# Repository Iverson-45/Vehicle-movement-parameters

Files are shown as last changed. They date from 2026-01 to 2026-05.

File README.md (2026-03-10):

Vehicle Movement Parameters Meter 
------

Authors: Jakub Litwin, Mateusz Prądziński, Adrian Andrószowski, Błażej Szkobel 
Overview

The goal of this project is to design and build a prototype device capable of measuring, calculating, and displaying real-time vehicle movement parameters. To ensure high data throughput, low latency, and a responsive UI, the system utilizes a Dual-MCU architecture that effectively splits the workload between sensor processing and data logging/display.
Calculated & Displayed Parameters:

    Speed: [km/h] 

    Acceleration: [m/s^2] (Instantaneous acceleration) 

    Power: [Hp] 

    Torque: [Nm] 

    Inclination: [°] (Pitch / Roll) 

Hardware Architecture

The device operates on two separate microcontrollers communicating via UART.

1. Main MCU (Data Processor)

    Microcontroller: STM32F411CEU6 

    Role: Handles all sensor data acquisition, scaling, filtration, and complex sensor fusion algorithms.

    Sensors: U-blox NEO-M8N (GPS) and BMI160 (IMU + Gyroscope).

2. Secondary MCU (Display & Logger)

    Microcontroller: STM32f303k8 

    Role: Receives processed numerical data from the Main MCU and handles the user interface.

    Peripherals: Drives a 2.0-inch TFT SPI Display and handles .csv data logging to a microSD card.

Firmware & Communication

    Main MCU: Programmed in low-level C (registers) to highly optimize the code for its specific tasks. It uses interrupt-driven peripherals to minimize delays and ensure smooth data reception. It synchronizes 100 data reads per second from the BMI160 and 5 reads per second from the GPS.

    Auxiliary MCU: Written in C utilizing the HAL library. It implements heavily optimized external libraries from GitHub for the ST7789 display and SPI SD card.

    Inter-MCU Communication: The two microcontrollers communicate via UART. At startup, they perform a handshake to initiate communication. The Aux MCU sends the user-defined vehicle mass to the Main MCU, and the Main MCU continuously streams back the calculated data.

How It Works: Algorithms & Calibration

To make the device user-friendly, it does not require perfectly leveled physical mounting inside the vehicle. Instead, the data passes through a complex algorithmic pipeline divided into three distinct phases:

Phase 1: Gravity Calibration While the vehicle is completely stationary, the device measures the Earth's gravitational pull to determine the gravity vector relative to the device's physical orientation. This establishes the true Z-axis (downward force).

Phase 2: Longitudinal Axis Calibration (Direction) The user performs a short, straight-line acceleration. The device detects this forward motion vector to define the X-axis (front). Using the cross product of these established forces, the software builds an orthonormal basis. This creates a 3D rotation matrix that mathematically rotates all raw sensor vectors to perfectly align with the vehicle's actual coordinate system, automatically compensating for any "crooked" mounting.

Phase 3: Active Operation During driving, raw data from the accelerometer and gyroscope is continuously transformed using the generated rotation matrix. The system calculates the device's tilt angles from the accelerometer and applies a Complementary Filter to fuse this data with the gyroscope readings for smooth, accurate inclination and acceleration outputs.
Current State & Future Development

Semester 1 Achievements:
A fully working prototype has been built that successfully handles instrument communication, calibration algorithms, the user interface, display presentation, and SD card .csv logging.

Next Steps (Semester 2 Goals): 

    Design a dedicated power supply section.

    Create a complete device schematic and custom PCB layout.

    Design a physical 3D enclosure/case.

    Conduct extensive real-world measurement tests.

    Develop PC software to visualize the saved telemetry data.

## Preliminary Measurement Results



During our initial field tests, the logged telemetry data was extracted and visualized using Python. We are pleased to report that the calculated power output closely aligns with the actual specifications of the vehicle used for testing.

**⚠️ Note:** Please keep in mind that this is an early prototype and not the final version of the system. The hardware architecture and calculation algorithms are still actively being refined. Further calibration, optimization, and extensive real-world validations are planned for the upcoming semester.

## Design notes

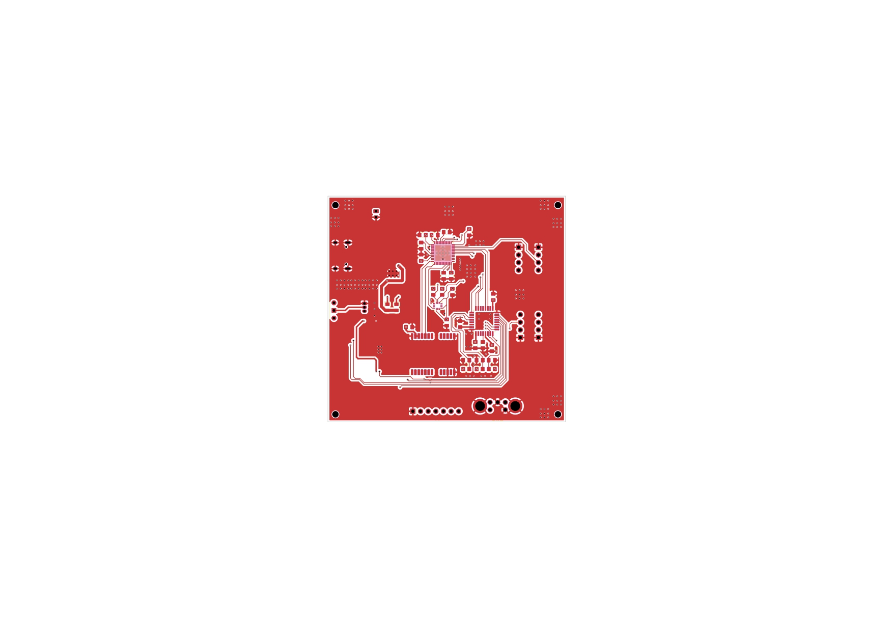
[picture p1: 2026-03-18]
Schematic/Screens/SIDEF_page-0001.jpg

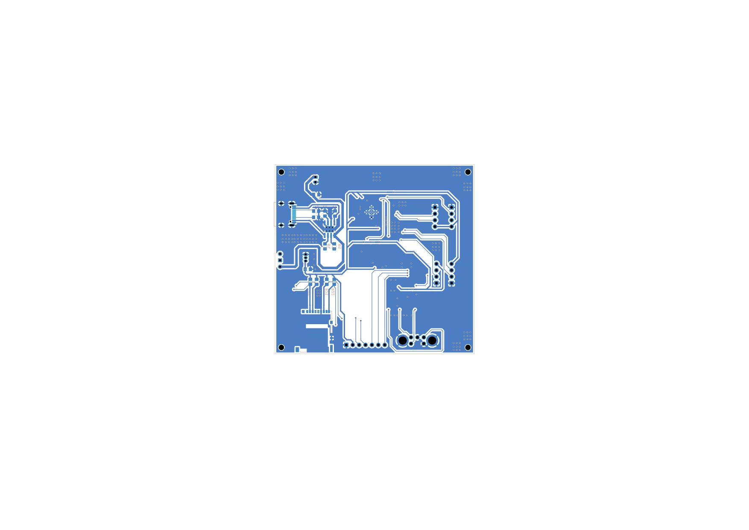
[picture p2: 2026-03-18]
Schematic/Screens/SIDEB_page-0001.jpg

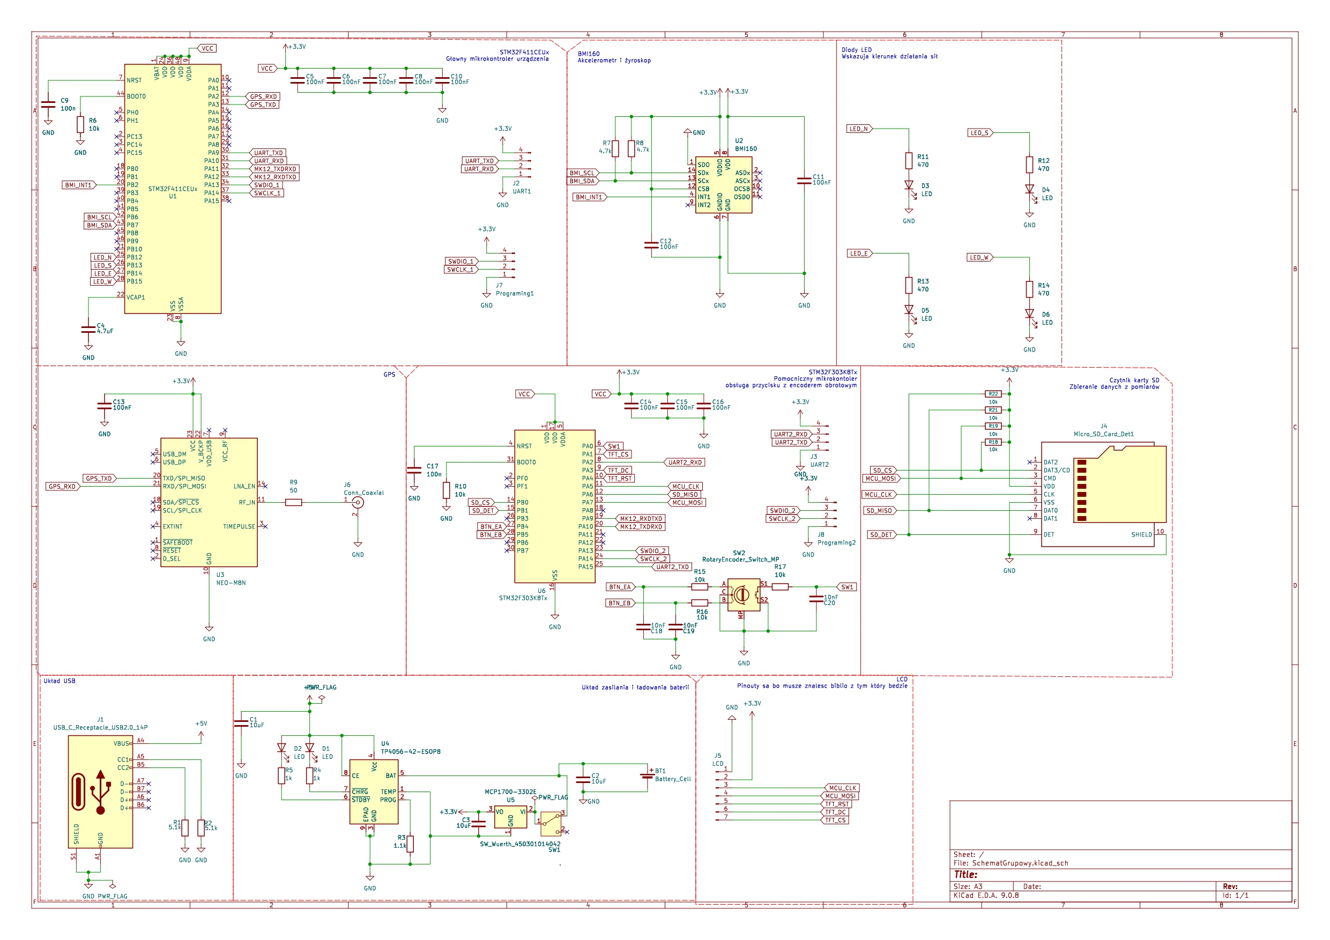
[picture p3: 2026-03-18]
Schematic/Screens/SchematGrupowy_page-0001.jpg

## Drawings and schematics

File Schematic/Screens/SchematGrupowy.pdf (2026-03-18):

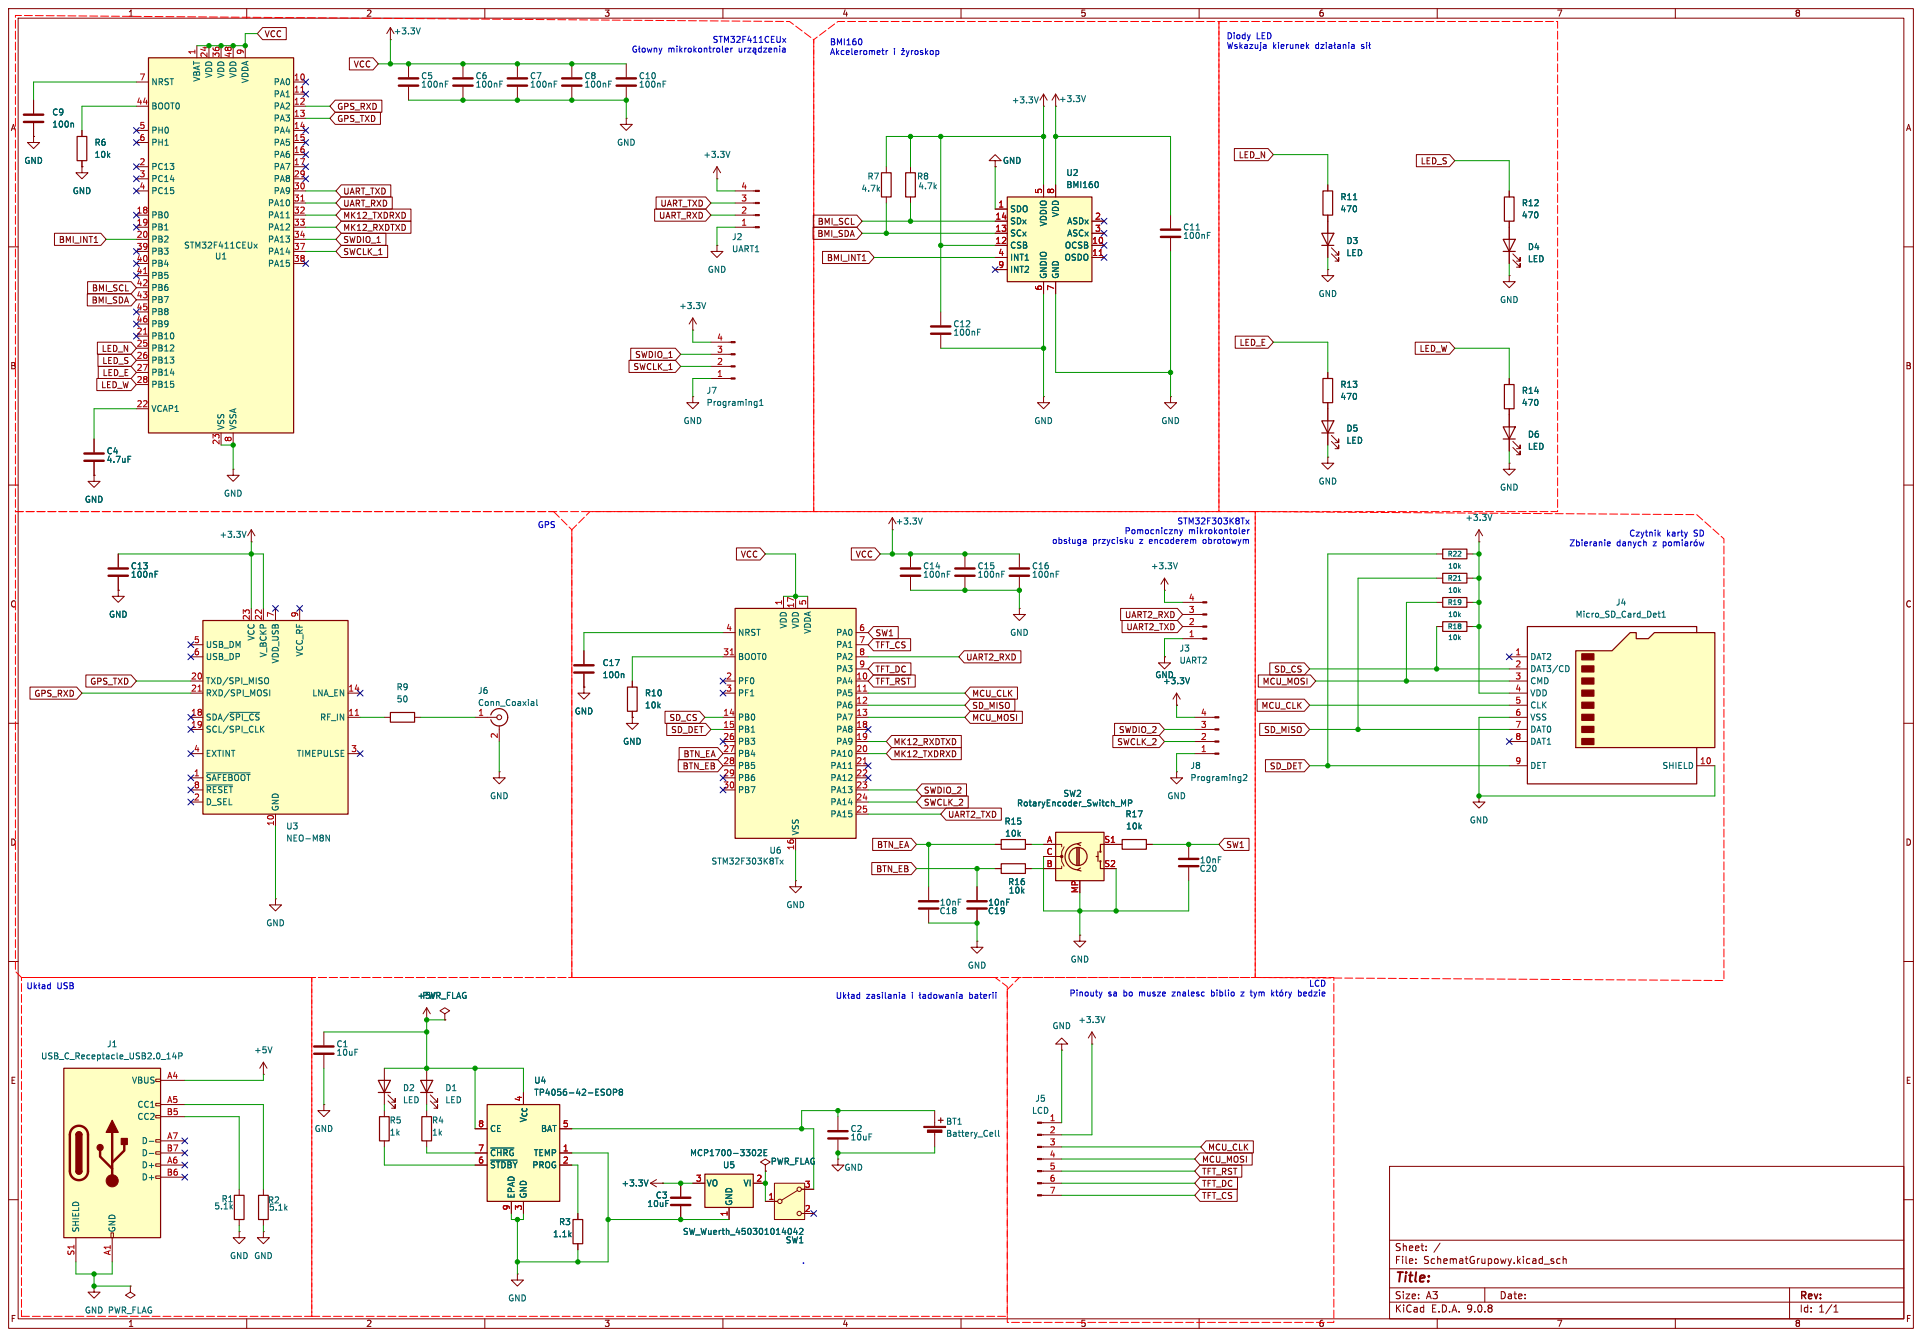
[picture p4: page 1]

1 VDD 24 VDD 36 VSS 23 VDD 48 VSSA

7 ASDx 2 ASCx 3 OCSB 10 OSDO 11 GND

7 ASDx 2 ASCx 3 OCSB 10 OSDO 11 U2BMI160 R19

3 BAT 5 TEMP 1 PROG 2 U4 TP4056-42-ESOP8 GND

Pinouty sa bo musze znalesc biblio z tym þÿktóry bedzie

Id: 1/1 Title: File: SchematGrupowy.kicad_sch Sheet: /

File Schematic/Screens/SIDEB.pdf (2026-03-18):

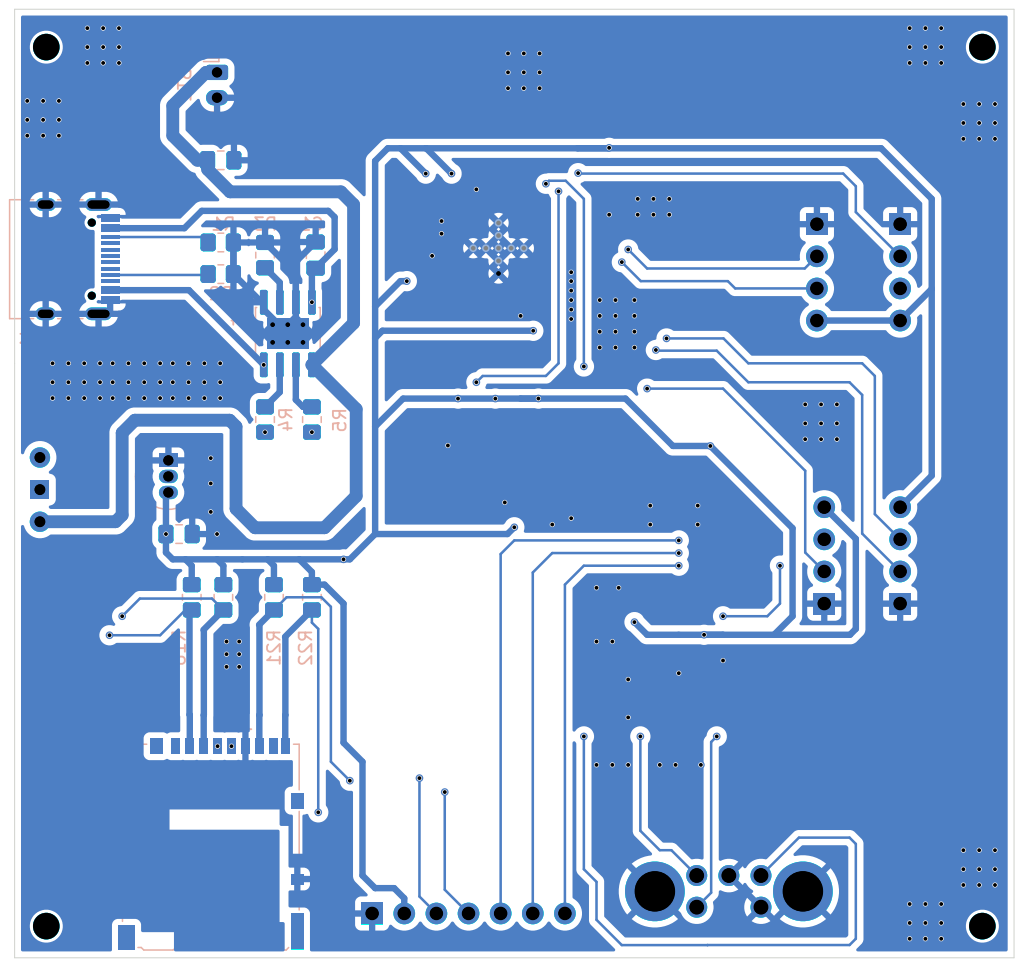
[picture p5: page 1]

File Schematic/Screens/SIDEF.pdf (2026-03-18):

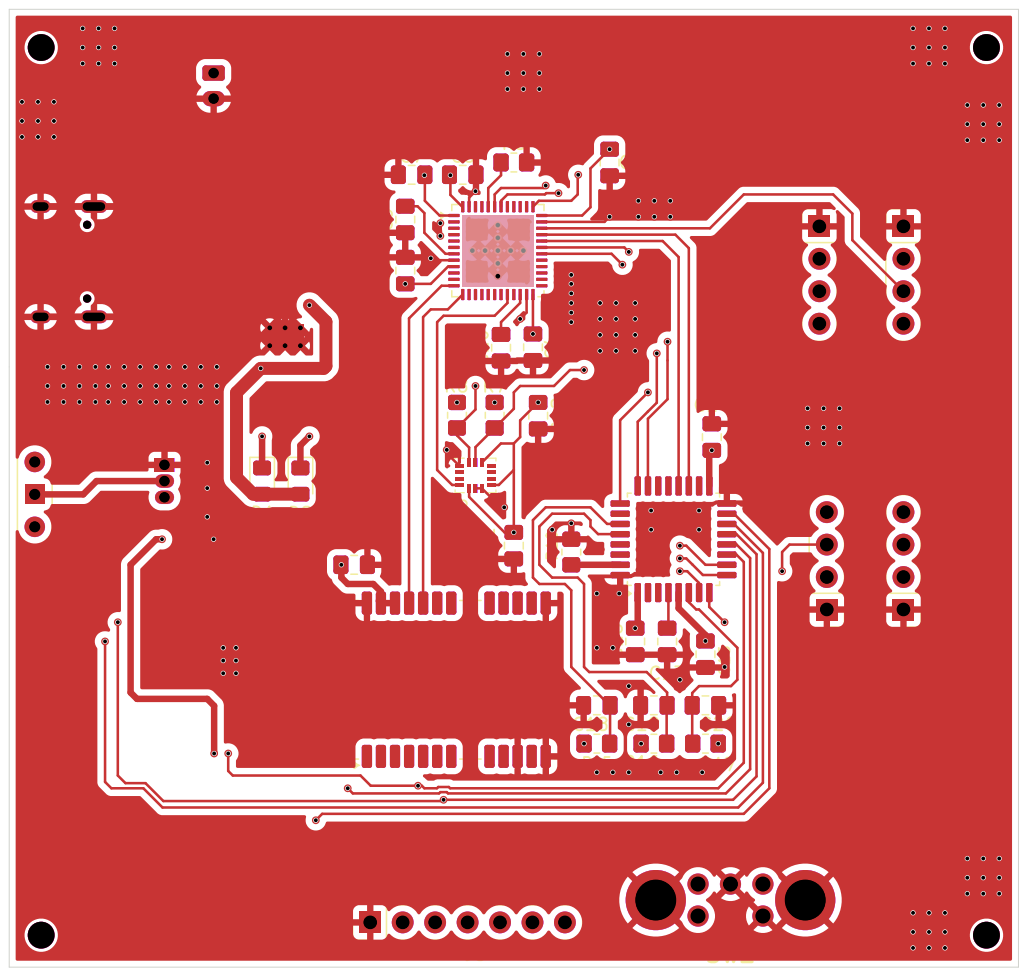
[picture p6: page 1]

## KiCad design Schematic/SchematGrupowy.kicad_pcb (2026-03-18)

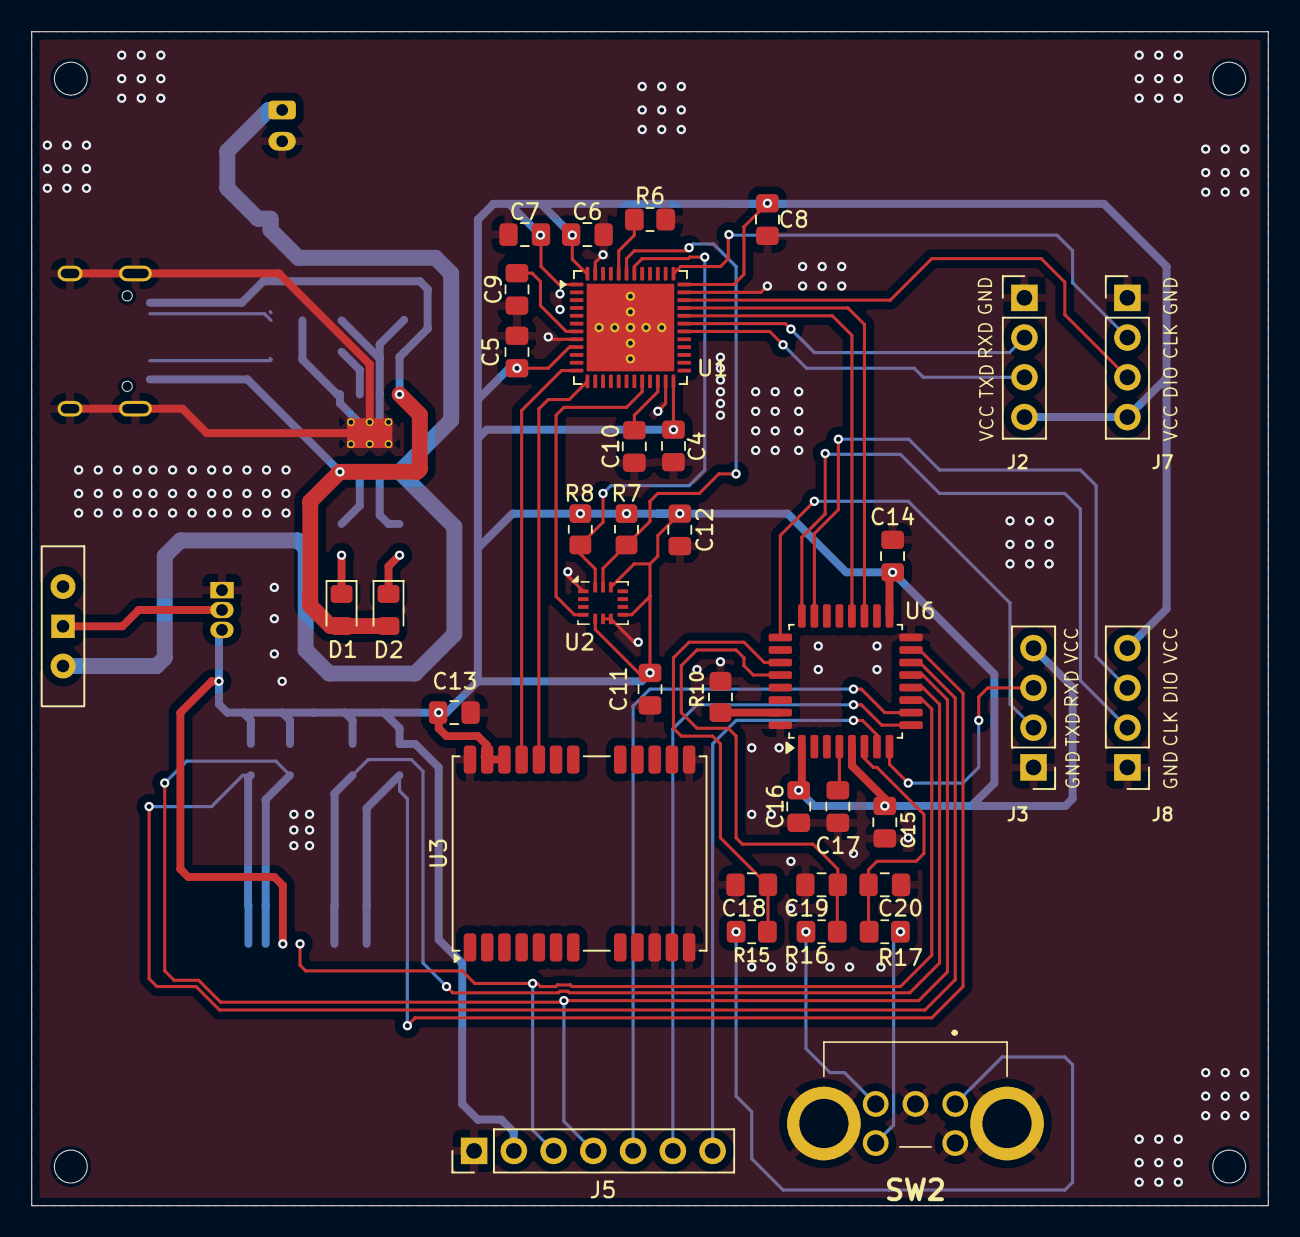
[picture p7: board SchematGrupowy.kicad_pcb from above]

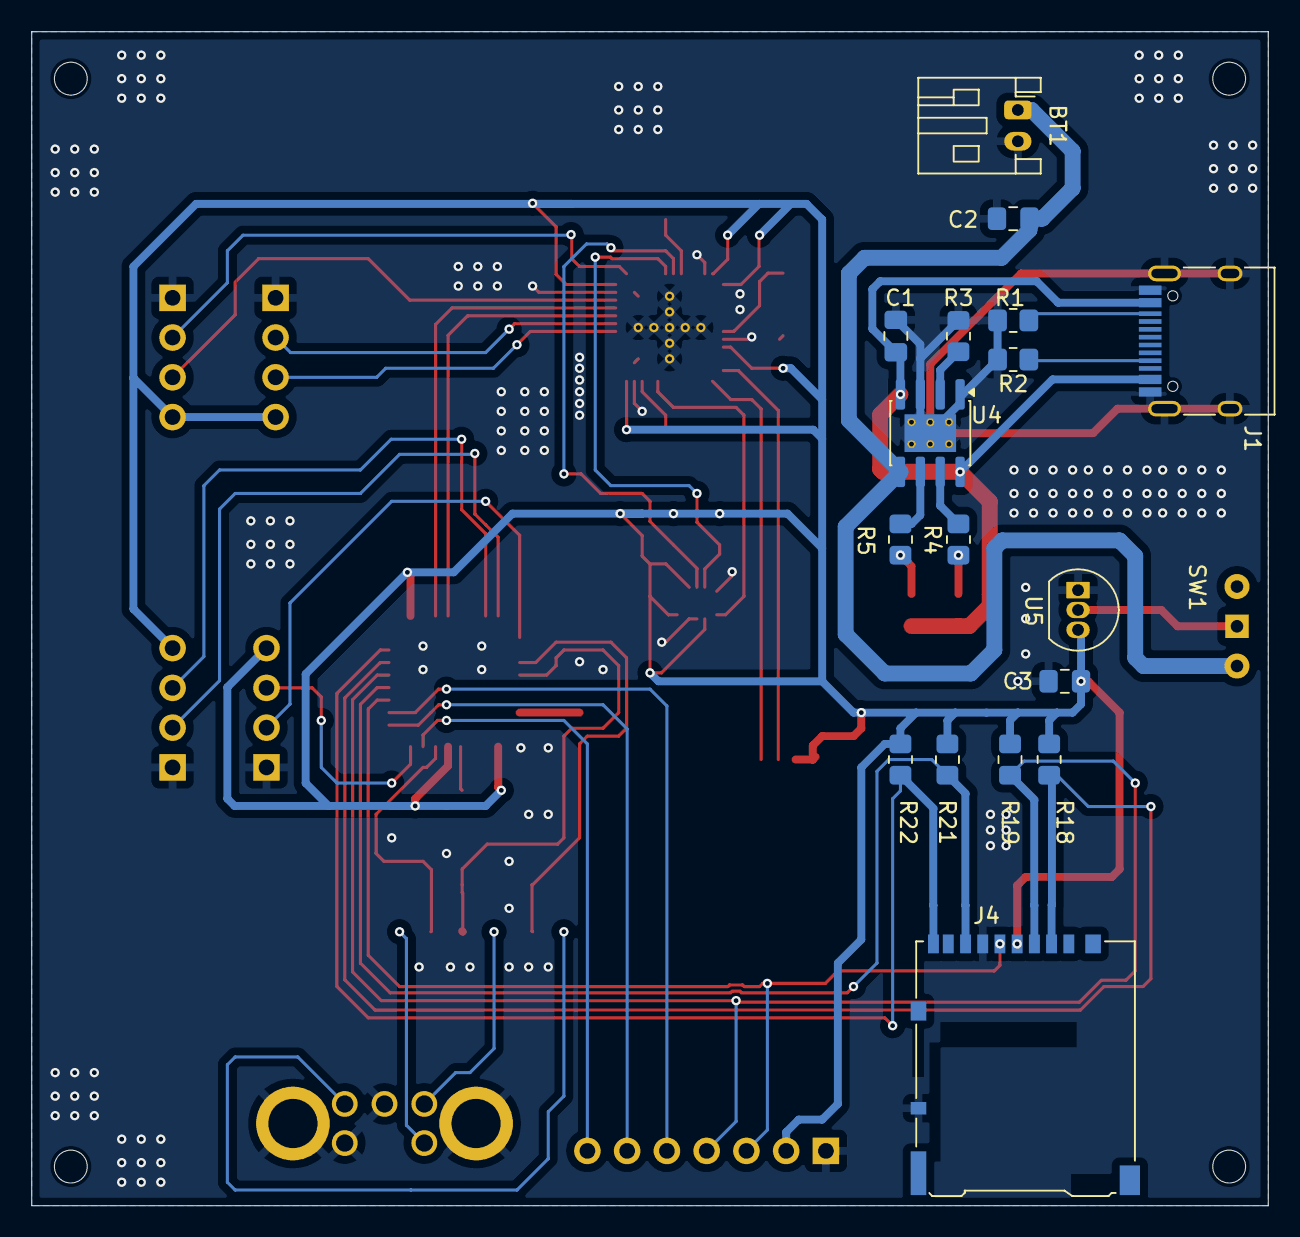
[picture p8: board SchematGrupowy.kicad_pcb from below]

Board: 2 copper layers, 79.0 x 75.0 mm, 54 parts (17 on the bottom side), 46 nets.

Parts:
BT1: Battery_Cell; JST_PH_S2B-PH-K_1x02_P2.00mm_Horizontal
C1, C2, C3: 10uF; C_0805_2012Metric_Pad1.18x1.45mm_HandSolder
C4: 4.7uF; C_0805_2012Metric_Pad1.18x1.45mm_HandSolder
C5, C6, C7, C8, C10, C11, C12, C13, C14, C15, C16: 100nF; C_0805_2012Metric_Pad1.18x1.45mm_HandSolder
C9, C17: 100n; C_0805_2012Metric_Pad1.18x1.45mm_HandSolder
C18, C19, C20: 10nF; C_0805_2012Metric_Pad1.18x1.45mm_HandSolder
D1, D2: LED; LED_0805_2012Metric_Pad1.15x1.40mm_HandSolder
J1: USB_C_Receptacle_USB2.0_14P; USB_C_Receptacle_HRO_TYPE-C-31-M-12
J2: UART1; PinHeader_1x04_P2.54mm_Vertical
J3: UART2; PinHeader_1x04_P2.54mm_Vertical
J4: Micro_SD_Card_Det1; microSD_HC_Hirose_DM3AT-SF-PEJM5
J5: LCD; PinHeader_1x07_P2.54mm_Vertical
J7: Programing1; PinHeader_1x04_P2.54mm_Vertical
J8: Programing2; PinHeader_1x04_P2.54mm_Vertical
R1, R2: 5.1k; R_0805_2012Metric_Pad1.20x1.40mm_HandSolder
R3: 1.1k; R_0805_2012Metric_Pad1.20x1.40mm_HandSolder
R4, R5: 1k; R_0805_2012Metric_Pad1.20x1.40mm_HandSolder
R6, R10, R15, R16, R17, R18, R19, R21, R22: 10k; R_0805_2012Metric_Pad1.20x1.40mm_HandSolder
R7, R8: 4.7k; R_0805_2012Metric_Pad1.20x1.40mm_HandSolder
SW1: SW_Wuerth_450301014042; SW_Slide-03_Wuerth-WS-SLTV_10x2.5x6.4_P2.54mm
SW2: RotaryEncoder_Switch_MP; EC11B15242AE
U1: STM32F411CEUx; QFN-48-1EP_7x7mm_P0.5mm_EP5.6x5.6mm
U2: BMI160; Bosch_LGA-14_3x2.5mm_P0.5mm
U3: NEO-M8N; ublox_NEO
U4: TP4056-42-ESOP8; SOIC-8-1EP_3.9x4.9mm_P1.27mm_EP2.41x3.3mm_ThermalVias
U5: MCP1700-3302E; TO-92_Inline
U6: STM32F303K8Tx; LQFP-32_7x7mm_P0.8mm

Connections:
+5V: C1.1, D1.2 (A), D2.2 (A), J1.A4 (VBUS), J1.A9 (VBUS), J1.B4 (VBUS), J1.B9 (VBUS), U4.4 (V_{CC}), U4.8 (CE)
BMI_INT1: U1.20 (PB2), U2.4 (INT1)
BMI_SCL: R8.2, U1.42 (PB6), U2.14 (SDx)
BMI_SDA: R7.2, U1.43 (PB7), U2.13 (SCx)
BTN_EA: C18.2, R15.1, U6.27 (PB4)
BTN_EB: C19.2, R16.2, U6.28 (PB5)
GND: BT1.2 (-), C1.2, C2.2, C3.2, C4.2, C5.2, C6.2, C7.2, C8.2, C9.2, C10.2, C11.2, C12.2, C13.2, C14.2, C15.2, C16.2, C17.2, C18.1, C19.1, C20.1, J1.A1 (GND), J1.A12 (GND), J1.B1 (GND), J1.B12 (GND), J1.S1 (SHIELD), J2.1, J3.1, J4.6 (VSS), J4.10 (SHIELD), J5.1, J7.1, J8.1, R1.2, R2.1, R3.2, R6.2, R10.2, SW2.C, SW2.MP, SW2.S2, U1.8 (VSSA), U1.23 (VSS), U1.35 (VSS), U1.47 (VSS), U1.49 (VSS), U2.1 (SDO), U2.6 (GNDIO), U2.7 (GND), U3.10 (GND), U3.12 (GND), U3.13 (GND), U3.24 (GND), U4.1 (TEMP), U4.3 (GND), U4.9 (EPAD), U5.1 (GND), U6.16 (VSS), U6.32 (VSS)
GPS_RXD: U1.12 (PA2), U3.21 (RXD/SPI_MOSI)
GPS_TXD: U1.13 (PA3), U3.20 (TXD/SPI_MISO)
MCU_CLK: J4.5 (CLK), J5.3, U6.11 (PA5)
MCU_MOSI: J4.3 (CMD), J5.4, R19.1, U6.13 (PA7)
MK12_RXDTXD: U1.33 (PA12), U6.19 (PA9)
MK12_TXDRXD: U1.32 (PA11), U6.20 (PA10)
unnamed: BT1.1 (+), C2.1, SW1.3 (A), U4.5 (BAT)
unnamed: D1.1 (K), R4.1
unnamed: D2.1 (K), R5.1
unnamed: J1.A5 (CC1), R2.2
unnamed: J1.B5 (CC2), R1.1
unnamed: R15.2, SW2.A
unnamed: R16.1, SW2.B
unnamed: R17.1, SW2.S1
unnamed: SW1.1 (B), U5.2 (VI)
unnamed: R6.1, U1.44 (BOOT0)
unnamed: C9.1, U1.7 (NRST)
unnamed: C4.1, U1.22 (VCAP1)
unnamed: R3.1, U4.2 (PROG)
unnamed: R4.2, U4.7 (~CHRG)
unnamed: R5.2, U4.6 (~STDBY)
unnamed: R10.1, U6.31 (BOOT0)
unnamed: C17.1, U6.4 (NRST)
SD_CS: J4.2 (DAT3/CD), R18.1, U6.14 (PB0)
SD_DET: J4.9 (DET), R22.1, U6.15 (PB1)
SD_MISO: J4.7 (DAT0), R21.1, U6.12 (PA6)
SW1: C20.2, R17.2, U6.6 (PA0)
SWCLK_1: J7.2, U1.37 (PA14)
SWCLK_2: J8.2, U6.24 (PA14)
SWDIO_1: J7.3, U1.34 (PA13)
SWDIO_2: J8.3, U6.23 (PA13)
TFT_CS: J5.7, U6.7 (PA1)
TFT_DC: J5.6, U6.9 (PA3)
TFT_RST: J5.5, U6.10 (PA4)
UART2_RXD: J3.3, U6.8 (PA2)
UART2_TXD: J3.2, U6.25 (PA15)
UART_RXD: J2.2, U1.31 (PA10)
UART_TXD: J2.3, U1.30 (PA9)
VCC: C3.1, C5.1, C6.1, C7.1, C8.1, C10.1, C11.1, C12.1, C13.1, C14.1, C15.1, C16.1, J2.4, J3.4, J4.4 (VDD), J5.2, J7.4, J8.4, R7.1, R8.1, R18.2, R19.2, R21.2, R22.2, U1.1 (VBAT), U1.9 (VDDA), U1.24 (VDD), U1.36 (VDD), U1.48 (VDD), U2.5 (VDDIO), U2.8 (VDD), U2.12 (CSB), U3.22 (V_BCKP), U3.23 (VCC), U5.3 (VO), U6.1 (VDD), U6.5 (VDDA), U6.17 (VDD)

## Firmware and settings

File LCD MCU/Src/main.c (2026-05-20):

#include "main.h"
#include "fatfs.h"
#include "dma.h"
#include "spi.h"
#include "usart.h"
#include "gpio.h"
#include "tim.h"
#include <string.h>
#include <stdio.h>
#include "utils.h"
#include "input_handler.h"
#include "sd_logger.h"
#include "app_ui.h"

#define RX_BUFFER_SIZE 64

typedef struct {
    int32_t speed;
    float   accel;
    int32_t pitch;
    int32_t roll;
    uint8_t count;
} AvgAccumulator;

AppState_t      currentAppState = STATE_INIT;
TelemetryData_t telemetryData = {0};

uint8_t  rxBufferIndex = 0;
uint8_t  rxByte;
volatile uint8_t isLineReady = 0;
uint8_t  uiRefreshRequest = 0;
char rxBuffer[RX_BUFFER_SIZE];

static AvgAccumulator sdAccumulator = {0};
static AvgAccumulator displayAccumulator = {0};

void SystemClock_Config(void);
void ProcessUARTLine(void);

int main(void)
{
  HAL_Init();
  SystemClock_Config();
  MX_GPIO_Init();
  MX_DMA_Init();
  MX_SPI1_Init();
  MX_USART1_UART_Init();
  MX_USART2_UART_Init();
  MX_TIM3_Init();
  MX_FATFS_Init();

  HAL_GPIO_WritePin(SD_CS_GPIO_Port, SD_CS_Pin, GPIO_PIN_SET);

  Input_Init(&htim3);
  Logger_Init();
  UI_Init();
  HAL_UART_Receive_IT(&huart1, &rxByte, 1);

  currentAppState = STATE_SPLASH;
  UI_ShowSplashScreen();

  uint32_t splashTimer = HAL_GetTick();
  uint8_t splashPromptDisplayed = 0;
  static AppState_t previousAppState = STATE_INIT;

  uint32_t lastPingTime = 0;
  uint32_t startTime = 0;

  static uint8_t calibrationStateInitialized = 0;
  static uint32_t calibrationTimer = 0;
  static uint32_t lastCalibPing = 0;

  while (1)
  {
      Input_Process(&currentAppState, &uiRefreshRequest);

      if (currentAppState == STATE_SPLASH) {
          if (!splashPromptDisplayed && (HAL_GetTick() - splashTimer > 1000)) {
              UI_ShowSplashPrompt();
              splashPromptDisplayed = 1;
          }
      }

      if (previousAppState == STATE_SPLASH && currentAppState == STATE_CONNECTING) {
          UI_ShowConnectionStatus(0);
          lastPingTime = HAL_GetTick();
          startTime = HAL_GetTick();
      }
      previousAppState = currentAppState;

      if (isLineReady) {
          ProcessUARTLine();
          isLineReady = 0;
          rxBufferIndex = 0;
          memset(rxBuffer, 0, RX_BUFFER_SIZE);
      }

      if (currentAppState == STATE_CONNECTING) {
          if (HAL_GetTick() - lastPingTime > 500) {
              uint8_t pingChar = 'd';
              HAL_UART_Transmit(&huart1, &pingChar, 1, 10);
              lastPingTime = HAL_GetTick();
          }
          if (HAL_GetTick() - startTime > 10000) {
              UI_ShowConnectionStatus(2);
              HAL_Delay(2000);
              NVIC_SystemReset();
          }
      }
      else if (currentAppState == STATE_CALIBRATION) {
          if (calibrationStateInitialized == 0) {
              calibrationTimer = HAL_GetTick();
              lastCalibPing = HAL_GetTick();
              calibrationStateInitialized = 1;
          }

          if ((HAL_GetTick() - calibrationTimer) > 2000) {
              if (HAL_GetTick() - lastCalibPing > 200) {
                  uint8_t msg = 'k';
                  HAL_UART_Transmit(&huart1, &msg, 1, 10);
                  lastCalibPing = HAL_GetTick();
              }
          }
      } else {
          calibrationStateInitialized = 0;
      }

      Logger_FlushBuffer();

      if (currentAppState == STATE_MEASUREMENT) {
          if (Logger_GetStatus() == SD_READY && !Logger_IsFileOpen()) {
               Logger_StartNewFile();
          }
      }

      if (uiRefreshRequest > 0 && currentAppState != STATE_CONNECTING) {
          UI_Update(currentAppState, &uiRefreshRequest, &telemetryData);
      }
  }
}

void HAL_UART_RxCpltCallback(UART_HandleTypeDef *huart) {
    if (huart->Instance == USART1) {
        if (rxByte == '\n' || rxByte == '\r') {
            if (rxBufferIndex > 0) { rxBuffer[rxBufferIndex] = 0; isLineReady = 1; }
        }
        else if (rxBufferIndex < RX_BUFFER_SIZE - 2) { rxBuffer[rxBufferIndex++] = rxByte; }
        else { rxBufferIndex = 0; }
        HAL_UART_Receive_IT(&huart1, &rxByte, 1);
    }
}

void HAL_UART_ErrorCallback(UART_HandleTypeDef *huart) {
    __HAL_UART_CLEAR_OREFLAG(huart);
    HAL_UART_Receive_IT(&huart1, &rxByte, 1);
}

void ProcessUARTLine(void) {
    if (currentAppState == STATE_CONNECTING) {
        if (strstr(rxBuffer, "ack")) {
            UI_ShowConnectionStatus(1); HAL_Delay(1000);
            currentAppState = STATE_MASS_INPUT; uiRefreshRequest = 2;
        }
    }
    else if (currentAppState == STATE_CALIBRATION) {
        if (strstr(rxBuffer, "c1")) {
            uint8_t msg = '1'; HAL_UART_Transmit(&huart1, &msg, 1, 10);
            uiRefreshRequest = 3;
        }
        else if (strstr(rxBuffer, "c2")) {
            uint8_t msg = '2'; HAL_UART_Transmit(&huart1, &msg, 1, 10);
            uiRefreshRequest = 4; HAL_Delay(500);
            Logger_StartNewFile(); currentAppState = STATE_MEASUREMENT; uiRefreshRequest = 2;
        }
    }
    else if (currentAppState == STATE_MEASUREMENT) {
        int16_t speed = 0, pitch = 0, roll = 0; float accel = 0.0f;
        char header = rxBuffer[0]; char* valStr = &rxBuffer[1];

        if      (header == 'v') speed = StringToInt(valStr);
        else if (header == 'a') accel = StringToFloat(valStr);
        else if (header == 'p') pitch = StringToInt(valStr);
        else if (header == 'r') roll  = StringToInt(valStr);

        telemetryData.timestamp = HAL_GetTick();

        if (header == 'v') telemetryData.speed = speed;
        if (header == 'a') telemetryData.accel = accel;
        if (header == 'p') telemetryData.pitch = pitch;
        if (header == 'r') telemetryData.roll  = roll;

        // Średnia tylko po odebraniu pełnego pakietu (ostatni znak to 'p')
        if (header == 'p')
        {
            sdAccumulator.speed += telemetryData.speed;
            sdAccumulator.accel += telemetryData.accel;
            sdAccumulator.pitch += telemetryData.pitch;
            sdAccumulator.roll  += telemetryData.roll;
            sdAccumulator.count++;

            if (sdAccumulator.count >= 2) {
                TelemetryData_t avgData;
                avgData.timestamp = telemetryData.timestamp;
                avgData.speed     = sdAccumulator.speed / 2;
                avgData.accel     = sdAccumulator.accel / 2.0f;
                avgData.pitch     = sdAccumulator.pitch / 2;
                avgData.roll      = sdAccumulator.roll / 2;
                Logger_AddData(&avgData);
                memset(&sdAccumulator, 0, sizeof(sdAccumulator));
            }

            displayAccumulator.speed += telemetryData.speed;
            displayAccumulator.accel += telemetryData.accel;
            displayAccumulator.pitch += telemetryData.pitch;
            displayAccumulator.roll  += telemetryData.roll;
            displayAccumulator.count++;

            if (displayAccumulator.count >= 8) {
                telemetryData.speed = displayAccumulator.speed / 8;
                telemetryData.accel = displayAccumulator.accel / 8.0f;
                telemetryData.pitch = displayAccumulator.pitch / 8;
                telemetryData.roll  = displayAccumulator.roll / 8;
                uiRefreshRequest = 1;
                memset(&displayAccumulator, 0, sizeof(displayAccumulator));
            }
        }
    }
}

/**
  * @brief System Clock Configuration
  * @retval None
  */
void SystemClock_Config(void)
{
    RCC_OscInitTypeDef RCC_OscInitStruct = {0};
    RCC_ClkInitTypeDef RCC_ClkInitStruct = {0};
    RCC_PeriphCLKInitTypeDef PeriphClkInit = {0};

    RCC_OscInitStruct.OscillatorType = RCC_OSCILLATORTYPE_HSI;
    RCC_OscInitStruct.HSIState = RCC_HSI_ON;
    RCC_OscInitStruct.HSICalibrationValue = RCC_HSICALIBRATION_DEFAULT;
    RCC_OscInitStruct.PLL.PLLState = RCC_PLL_ON;
    RCC_OscInitStruct.PLL.PLLSource = RCC_PLLSOURCE_HSI;
    RCC_OscInitStruct.PLL.PLLMUL = RCC_PLL_MUL16;
    if (HAL_RCC_OscConfig(&RCC_OscInitStruct) != HAL_OK)
    {
      Error_Handler();
    }

    RCC_ClkInitStruct.ClockType = RCC_CLOCKTYPE_HCLK | RCC_CLOCKTYPE_SYSCLK |
                                   RCC_CLOCKTYPE_PCLK1 | RCC_CLOCKTYPE_PCLK2;
    RCC_ClkInitStruct.SYSCLKSource = RCC_SYSCLKSOURCE_PLLCLK;
    RCC_ClkInitStruct.AHBCLKDivider = RCC_SYSCLK_DIV1;
    RCC_ClkInitStruct.APB1CLKDivider = RCC_HCLK_DIV2;
    RCC_ClkInitStruct.APB2CLKDivider = RCC_HCLK_DIV1;
    if (HAL_RCC_ClockConfig(&RCC_ClkInitStruct, FLASH_LATENCY_2) != HAL_OK)
    {
      Error_Handler();
    }

    PeriphClkInit.PeriphClockSelection = RCC_PERIPHCLK_USART1;
    PeriphClkInit.Usart1ClockSelection = RCC_USART1CLKSOURCE_PCLK1;
    if (HAL_RCCEx_PeriphCLKConfig(&PeriphClkInit) != HAL_OK)
    {
      Error_Handler();
    }
}

/**
  * @brief  This function is executed in case of error occurrence.
  * @retval None
  */
void Error_Handler(void)
{
  __disable_irq();
  while (1)
  {
  }
}

#ifdef USE_FULL_ASSERT
void assert_failed(uint8_t *file, uint32_t line)
{
}
#endif /* USE_FULL_ASSERT */

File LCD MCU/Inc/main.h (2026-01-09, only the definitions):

#define MCO_Pin GPIO_PIN_0
#define MCO_GPIO_Port GPIOF
#define ENC_BTN_Pin GPIO_PIN_0
#define ENC_BTN_GPIO_Port GPIOA
#define TFT_CS_Pin GPIO_PIN_1
#define TFT_CS_GPIO_Port GPIOA
#define VCP_TX_Pin GPIO_PIN_2
#define VCP_TX_GPIO_Port GPIOA
#define TFT_DC_Pin GPIO_PIN_3
#define TFT_DC_GPIO_Port GPIOA
#define TFT_RST_Pin GPIO_PIN_4
#define TFT_RST_GPIO_Port GPIOA
#define SD_CS_Pin GPIO_PIN_0
#define SD_CS_GPIO_Port GPIOB
#define SD_DETECT_Pin GPIO_PIN_1
#define SD_DETECT_GPIO_Port GPIOB
#define UART_TX_Pin GPIO_PIN_9
#define UART_TX_GPIO_Port GPIOA
#define UART_RX_Pin GPIO_PIN_10
#define UART_RX_GPIO_Port GPIOA
#define SWDIO_Pin GPIO_PIN_13
#define SWDIO_GPIO_Port GPIOA
#define SWCLK_Pin GPIO_PIN_14
#define SWCLK_GPIO_Port GPIOA
#define VCP_RX_Pin GPIO_PIN_15
#define VCP_RX_GPIO_Port GPIOA

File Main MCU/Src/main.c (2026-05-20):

#include "main.h"
#include <string.h>
#include <stdio.h>
#include <math.h>

typedef struct {
    float x, y, z;
} vector;

typedef enum {
    CAL_STATE_WAIT_HANDSHAKE,
    CAL_STATE_WAIT_START_CMD,
    CAL_STATE_GRAVITY_CALC,
    CAL_STATE_WAIT_STEP1_CONFIRM,
    CAL_STATE_MOVEMENT_CALC,
    CAL_STATE_WAIT_STEP2_CONFIRM,
    CAL_STATE_RUNNING
} CalibrationFlow_t;

volatile CalibrationFlow_t current_flow = CAL_STATE_WAIT_HANDSHAKE;
volatile uint8_t lcd_ack_state = 0;

float RotationMatrix[3][3];
const float dt = 0.01f;
const float alpha = 0.02f;

char accbuf[16];
char rollbuf[16];
char pitchbuf[16];
char speedbuf[16];

void SystemInit(void) {
    SCB->CPACR |= (0xF << 20);
}

float VectorLength(vector vec) {
    return sqrtf((vec.x * vec.x) + (vec.y * vec.y) + (vec.z * vec.z));
}

void NormalizeVector(vector *vec);
vector VectorCross(vector a, vector b);
vector RotatedVector(float rotation[3][3], vector vec);

int main(void)
{
    SystemClock_Config();
    SysTick_Config(98000000 / 1000000);

    Uart6_Init();
    Uart2_Init();
    Uart1_Init();
    I2C_Init();
    Init_GPIO_Interrupt();
    GPS_Init();
    BMI160_Init();

    UART_SendString(USART1, "Measurement MCU: Booted.\n\r");

    BMI160_Data imu;
    vector raw_acc, raw_gyro, raw_acc_sum = {0.0f}, gravity_average = {0.0f}, gravity_versor = {0.0f};
    vector linear_accel, body_accel, body_incline;

    uint8_t sample_count = 0;
    uint8_t tick_counter = 0; // Licznik Non-Blocking dla UART

    float roll = 0.0f, pitch = 0.0f, acceleration;
    int16_t current_speed = 0;

    while (1)
    {
        /* GPS Parsing */
        if (gps_ready_flag) {
            current_speed = (int16_t)ParseSpeed();
            sprintf(speedbuf, "v%d\n", current_speed);
            UART_SendString(USART6, speedbuf);
            gps_ready_flag = 0;
        }

        /* Check for Reset */
        if (lcd_ack_state == 1 && current_flow == CAL_STATE_RUNNING) {
             current_flow = CAL_STATE_WAIT_HANDSHAKE;
        }

        /* IMU Data Ready (Ticking at ~100Hz) */
        if (bmi160_data_ready)
        {
            BMI160_ReadData(&imu);
            raw_acc.x = imu.ax; raw_acc.y = imu.ay; raw_acc.z = imu.az;
            raw_gyro.x = imu.gx; raw_gyro.y = imu.gy; raw_gyro.z = imu.gz;

            tick_counter++; // Rośnie o 1 co 10ms

            switch (current_flow)
            {
                case CAL_STATE_WAIT_HANDSHAKE:
                    if (lcd_ack_state == 1) {
                        lcd_ack_state = 0;
                        current_flow = CAL_STATE_WAIT_START_CMD;
                    }
                    break;

                case CAL_STATE_WAIT_START_CMD:
                    // Wysyłaj 'ack' co 200ms (20 ticków) bez opóźniania procesora!
                    if (tick_counter % 20 == 0) {
                        UART_SendString(USART6, "ack\n");
                    }

                    if (lcd_ack_state == 4) {
                        lcd_ack_state = 0;
                        sample_count = 0;
                        raw_acc_sum.x = 0; raw_acc_sum.y = 0; raw_acc_sum.z = 0;
                        current_flow = CAL_STATE_GRAVITY_CALC;
                    }
                    break;

                case CAL_STATE_GRAVITY_CALC:
                    raw_acc_sum.x += raw_acc.x;
                    raw_acc_sum.y += raw_acc.y;
                    raw_acc_sum.z += raw_acc.z;

                    if (++sample_count >= 100) {
                        gravity_average.x = raw_acc_sum.x / sample_count;
                        gravity_average.y = raw_acc_sum.y / sample_count;
                        gravity_average.z = raw_acc_sum.z / sample_count;
                        gravity_versor = gravity_average;
                        NormalizeVector(&gravity_versor);

                        lcd_ack_state = 0;
                        current_flow = CAL_STATE_WAIT_STEP1_CONFIRM;
                    }
                    break;

                case CAL_STATE_WAIT_STEP1_CONFIRM:
                    // Spamu co 200ms dopóki LCD nie potwierdzi
                    if (tick_counter % 20 == 0) {
                        UART_SendString(USART6, "c1\n");
                    }
                    if (lcd_ack_state == 2) {
                        lcd_ack_state = 0;
                        current_flow = CAL_STATE_MOVEMENT_CALC;
                    }
                    break;

                case CAL_STATE_MOVEMENT_CALC:
                    linear_accel.x = raw_acc.x - gravity_average.x;
                    linear_accel.y = raw_acc.y - gravity_average.y;
                    linear_accel.z = raw_acc.z - gravity_average.z;

                    if (VectorLength(linear_accel) > 2.5f) {
                        vector z_axis = gravity_versor;
                        vector movement = linear_accel;
                        NormalizeVector(&movement);
                        vector y_axis = VectorCross(z_axis, movement);
                        NormalizeVector(&y_axis);
                        vector x_axis = VectorCross(y_axis, z_axis);
                        NormalizeVector(&x_axis);

                        RotationMatrix[0][0] = x_axis.x; RotationMatrix[0][1] = x_axis.y; RotationMatrix[0][2] = x_axis.z;
                        RotationMatrix[1][0] = y_axis.x; RotationMatrix[1][1] = y_axis.y; RotationMatrix[1][2] = y_axis.z;
                        RotationMatrix[2][0] = z_axis.x; RotationMatrix[2][1] = z_axis.y; RotationMatrix[2][2] = z_axis.z;

                        lcd_ack_state = 0;
                        current_flow = CAL_STATE_WAIT_STEP2_CONFIRM;
                    }
                    break;

                case CAL_STATE_WAIT_STEP2_CONFIRM:
                    if (tick_counter % 20 == 0) {
                        UART_SendString(USART6, "c2\n");
                    }
                    if (lcd_ack_state == 3) {
                        lcd_ack_state = 0;
                        current_flow = CAL_STATE_RUNNING;
                    }
                    break;

                case CAL_STATE_RUNNING:
                    body_accel = RotatedVector(RotationMatrix, raw_acc);
                    body_incline = RotatedVector(RotationMatrix, raw_gyro);

                    float acc_roll = atan2f(body_accel.y, body_accel.z) * 57.296f;
                    float acc_pitch = atan2f(-body_accel.x, sqrtf(body_accel.y*body_accel.y + body_accel.z*body_accel.z)) * 57.296f;

                    if(fabsf(body_accel.x) > 0.8f) {
                        roll  = roll  + body_incline.x * dt;
                        pitch = pitch + body_incline.y * dt;
                    } else {
                        roll  = (1.0f - alpha) * (roll  + body_incline.x * dt) + (alpha * acc_roll);
                        pitch = (1.0f - alpha) * (pitch + body_incline.y * dt) + (alpha * acc_pitch);
                    }
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

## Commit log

2025-11-25 Updated main
    Added velocity updating on LCD and UART-PC debuging
2025-11-25 moved uart1.c & uart2.c functions to uart.c
2025-11-25 Moved uart1.h & uart2.h to uart.h
2025-11-25 Update and rename ubx.c to gps.c
    GPS functions from uart1.c are moved to gps.c
2025-11-25 Update README
    Added a section for stages in README.
2025-11-25 Add ST7567_SetRotation function prototype
2025-11-25 Add BMI160 sensor driver implementation
    This file implements functions to read and write data from the BMI160 sensor, initialize it, and read accelerometer and gyroscope data.
2025-11-26 Added interrupts for imu readings
2025-11-26 Implement GPIO interrupt initialization for PA1
    Added GPIO initialization for external interrupt on PA1.
2025-11-26 Add i2c and clock config
2025-11-28 Update main
    Added GPS speed logging functionality to UART output.
2025-12-15 inclination relative to the device start position
2026-01-06 Implement USART6 IRQ and refine acceleration logic
    Added USART6 interrupt handler and adjusted acceleration calculation.
2026-01-09 Added encoder, sd card support. Created UI.
2026-03-10 Refactor main.c for filter implementation
    Fixed problems with fusion filter. Added adaptive filter.
    [main.c]
2026-03-11 Added schematic
    [SchematGrupowy.kicad_pcb, SchematGrupowy.kicad_sch]
2026-03-13 Apply final touches to PCB design
    [SchematGrupowy.kicad_pcb]
2026-03-14 Resolve DRC issues and pour ground planes
    [SchematGrupowy.kicad_pcb, SchematGrupowy.kicad_sch]
2026-03-17 Added descriptions for programming/uart pins
    [SchematGrupowy.kicad_pcb]
2026-03-18 Added Gerbres,screens and footprint fixes
    [SchematGrupowy-B_Cu.gbl, SchematGrupowy-B_Mask.gbs, SchematGrupowy-B_Paste.gbp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]

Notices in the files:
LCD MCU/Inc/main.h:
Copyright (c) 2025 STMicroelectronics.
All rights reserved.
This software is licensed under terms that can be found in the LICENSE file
